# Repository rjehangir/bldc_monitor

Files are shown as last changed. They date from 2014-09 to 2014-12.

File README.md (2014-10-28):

BLDC Monitor
========

The BLDC Monitor is an Arduino compatible board with voltage, current, and RPM sensors for a three-phase brushless motor. The board has components to monitor two motors simultaneously. The software is written in C++ and communicates with a Python program through serial. An ncurses interface allows the motor to be controlled with the arrow keys on the keyboard. Data is displayed in the terminal and also plotted live through Plot.ly.

##Features

* Atmega328p microcontroller
* RPM sensor that uses motor wire for input. An optoisolator protects the rest of the circuit and an active low-pass filter removes high frequency PWM and converts the EMF wave to a binary signal.
* Allegro hall effect current sensors for accurate current measurements
* Measures 2 motors simultaneously

##Interface

The interface is written in Python. It uses the curses, crcmod, serial, and plotly libraries. To run the interface:

```bash
./bldc_monitor.py -p [serial port] -o [csv file to write (optional)]
```

##Releases

TBD

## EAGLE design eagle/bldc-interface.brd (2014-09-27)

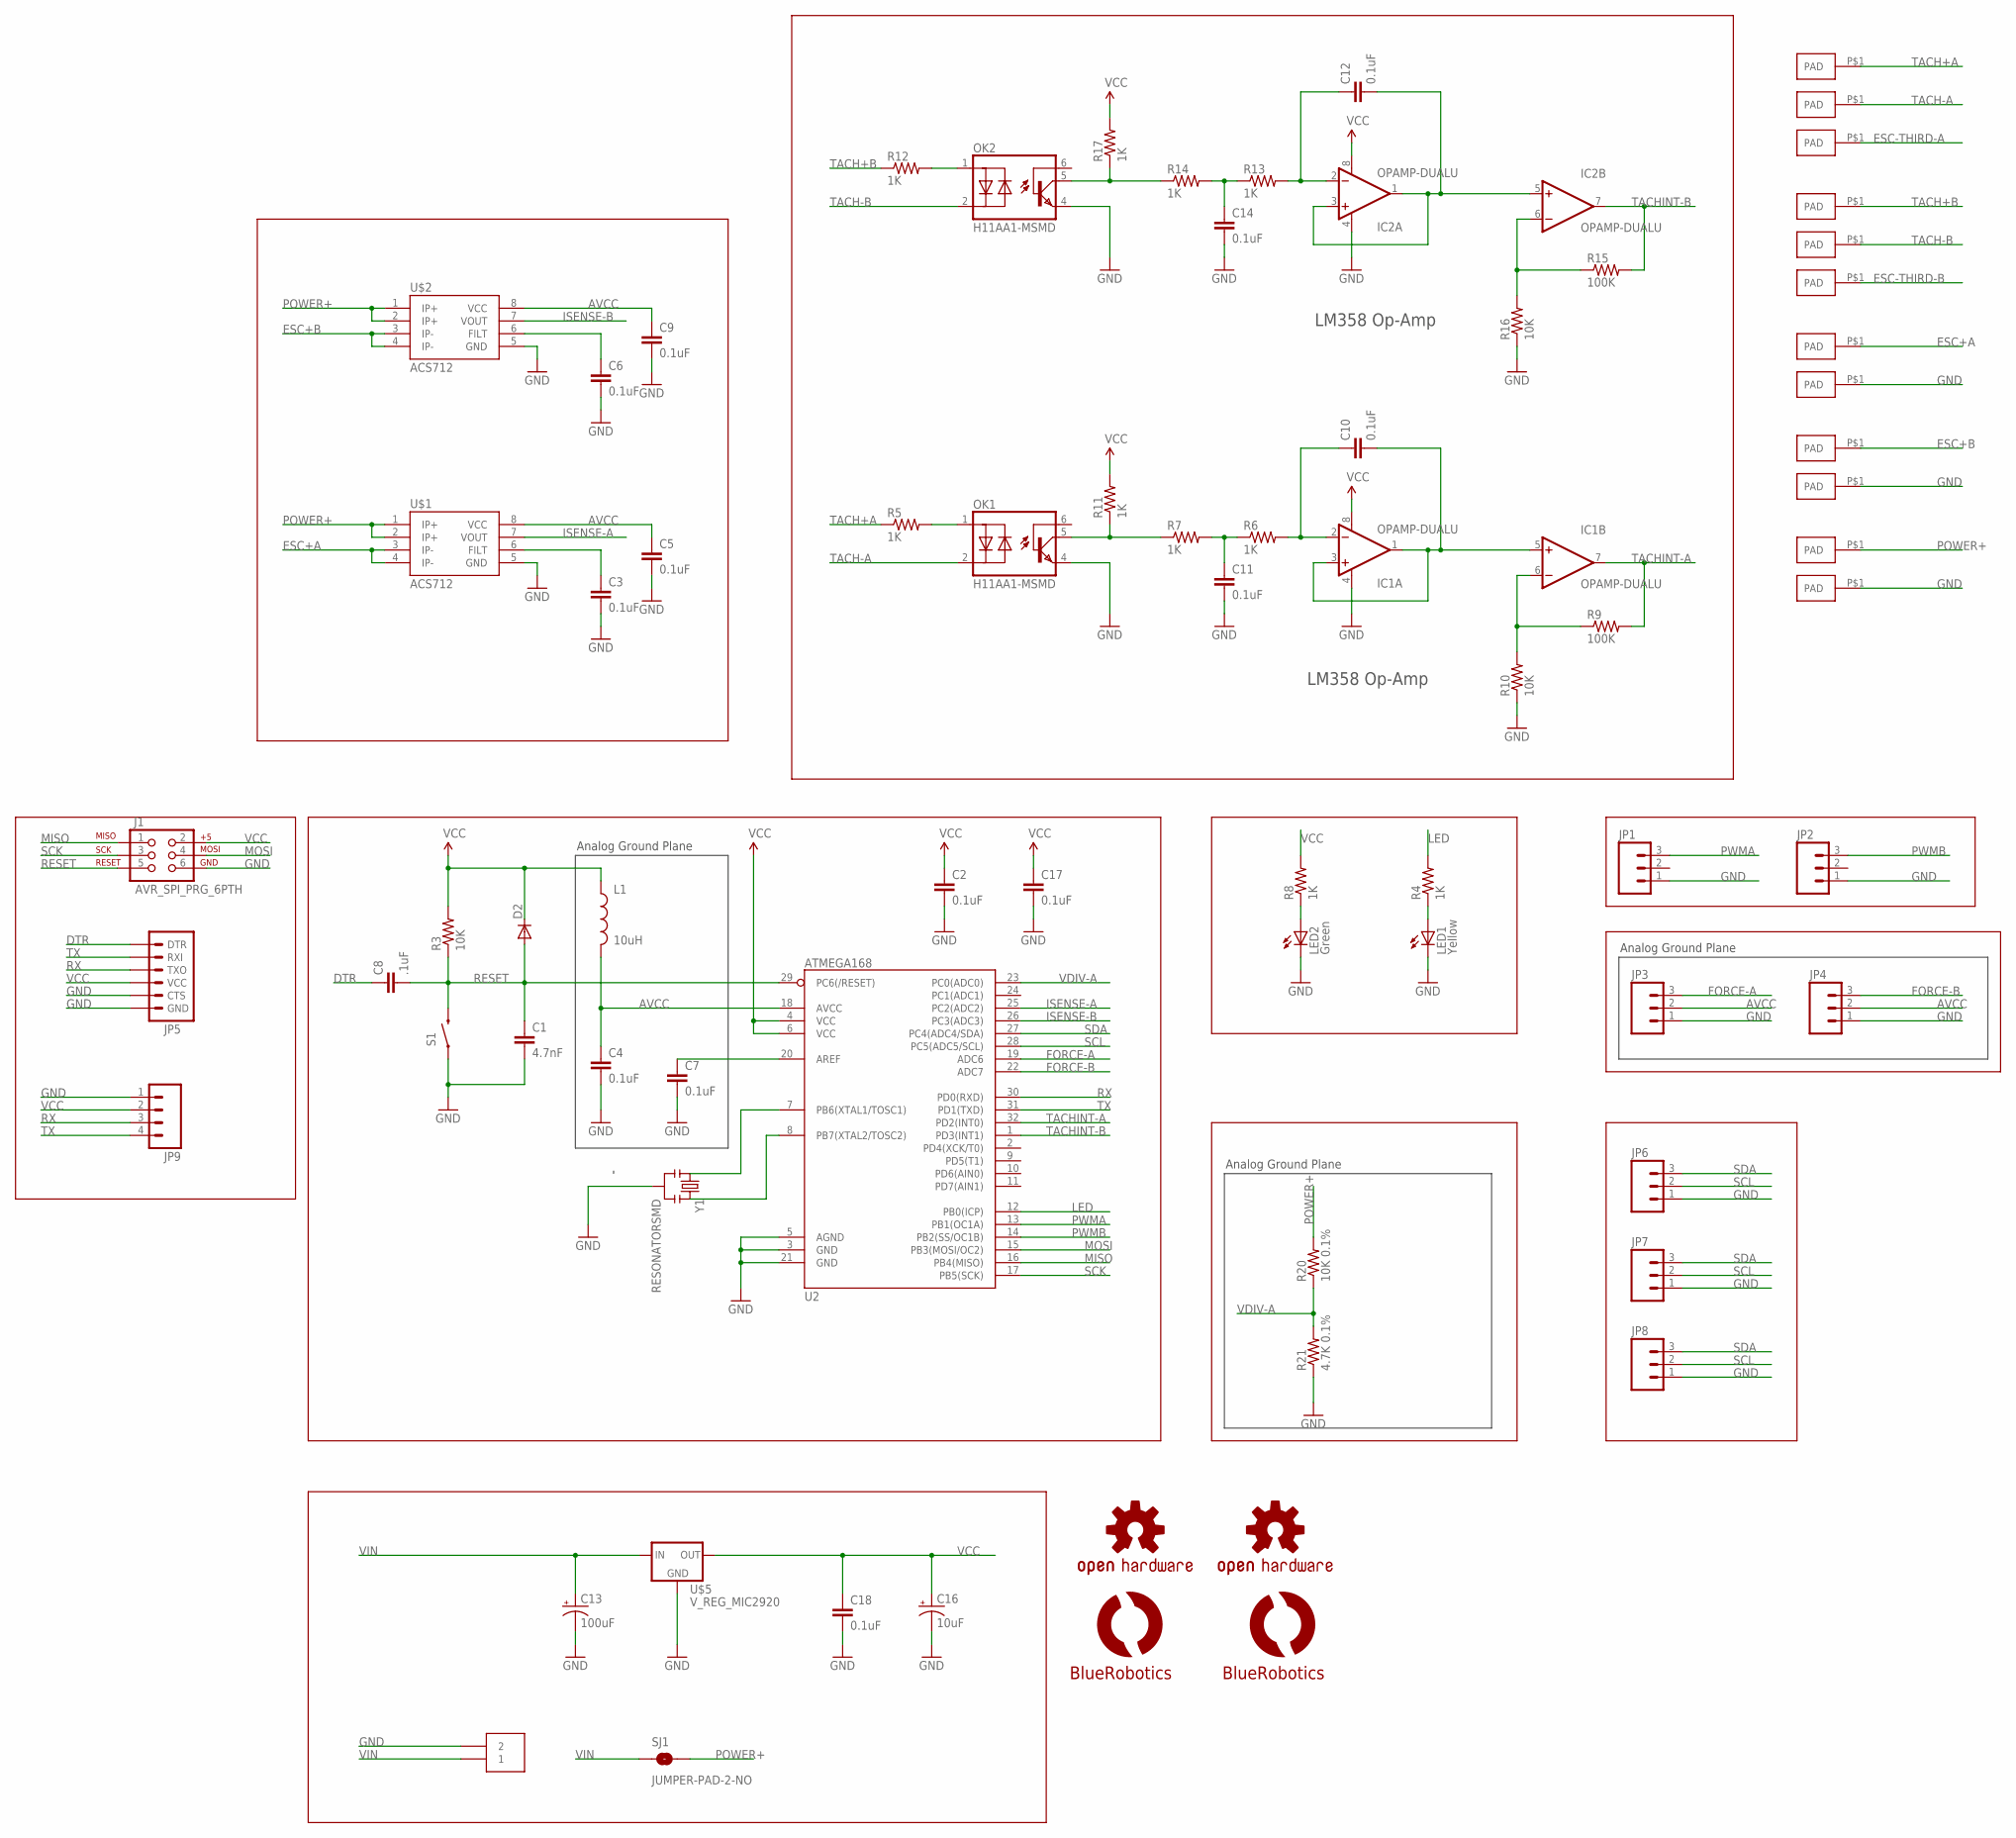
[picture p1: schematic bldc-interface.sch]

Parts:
C1: 4.7nF; 0603-CAP
C2, C3, C4, C5, C6, C7, C9, C10, C11, C12, C14, C17, C18: 0.1uF; 0603-CAP
C8: .1uF; 0603-CAP
C13: 100uF; CPOL-RADIAL-100UF-25V
C16: 10uF; EIA3216
D2: DIODESOD; SOD-323
IC1, IC2: OPAMP-DUALU; SO08
J1: AVR_SPI_PRG_6PTH; 2X3
JP1, JP2, JP3, JP4, JP6, JP7, JP8: M03PTH; 1X03
JP5: ARDUINO_SERIAL_PROGRAMPTH; 1X06
JP9: M04PTH; 1X04
L1: 10uH; 0603
LED1: Yellow; LED-0603
LED2: Green; LED-0603
LOGO1: OSHW-LOGOS; OSHW-LOGO-S
LOGO2: OSHW-LOGOM; OSHW-LOGO-M
OK1, OK2: H11AA1-MSMD; DIL6-SMD
R3, R10, R16: 10K; 0603-RES
R4, R6, R7, R8, R11, R13, R14, R17: 1K; 0603-RES
R5, R12: 1K; R2512
R9, R15: 100K; 0603-RES
R20: 10K 0.1%; 0603-RES
R21: 4.7K 0.1%; 0603-RES
S1: reset; TACTILE_SWITCH_SMD
SJ1: JUMPER-PAD-2-NO; PAD-JUMPER-2-NO_NO_SILK
U2: ATMEGA168; TQFP32-08
U$1, U$2: ACS712; SO08
U$3: TERMINAL-25MM-WEID; LSF-SMT-5MM-2
U$4, U$6, U$7, U$8, U$9, U$10, U$11, U$12, U$13, U$14, U$15, U$16: PADLARGE-ONE-SIDE; PAD-0.2X0.3-ONE-SIDE
U$5: V_REG_MIC2920; SOT223
U$17: LOGOBR-LOGO-M; BR-LOGO-MEDIUM
U$18: LOGOBR-LOGO-S; BR-LOGO-SMALL
Y1: RESONATORSMD; RESONATOR-SMD

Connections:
AVCC: C4.1, C5.1, C9.1, JP3.2, JP4.2, L1.2, U2.18 (AVCC), U$1.8 (VCC), U$2.8 (VCC)
DTR: C8.1, JP5.1 (DTR)
ESC+A: U$1.3 (IP-), U$1.4 (IP-), U$13.P$1
ESC+B: U$2.3 (IP-), U$2.4 (IP-), U$15.P$1
ESC-THIRD-A: U$9.P$1
ESC-THIRD-B: U$12.P$1
FORCE-A: JP3.3, U2.19 (ADC6)
FORCE-B: JP4.3, U2.22 (ADC7)
GND: C1.2, C2.2, C3.2, C4.2, C5.2, C6.2, C7.2, C9.2, C11.2, C13.2 (-), C14.2, C16.C (-), C17.2, C18.2, IC1.4 (V-), IC2.4 (V-), J1.6, JP1.1, JP2.1, JP3.1, JP4.1, JP5.5 (CTS), JP5.6 (GND), JP6.1, JP7.1, JP8.1, JP9.1, LED1.C, LED2.C, OK1.4 (EMI), OK2.4 (EMI), R10.1, R16.1, R21.1, S1.1, U2.3 (GND), U2.5 (AGND), U2.21 (GND), U$1.5 (GND), U$2.5 (GND), U$3.2, U$3.4 (2), U$5.2 (GND), U$8.P$1, U$14.P$1, U$16.P$1, Y1.2
ISENSE-A: U2.25 (PC2(ADC2)), U$1.7 (VOUT)
ISENSE-B: U2.26 (PC3(ADC3)), U$2.7 (VOUT)
LED: R4.2, U2.12 (PB0(ICP))
MISO: J1.1, U2.16 (PB4(MISO))
MOSI: J1.4, U2.15 (PB3(MOSI/OC2))
unnamed: C6.1, U$2.6 (FILT)
unnamed: C3.1, U$1.6 (FILT)
unnamed: LED1.A, R4.1
unnamed: C10.1, IC1.2 (-IN), R6.2
unnamed: C10.2, IC1.1 (OUT), IC1.3 (+IN), IC1.5 (+IN)
unnamed: IC1.6 (-IN), R9.1, R10.2
unnamed: C11.1, R6.1, R7.2
unnamed: C7.1, U2.20 (AREF)
unnamed: U2.7 (PB6(XTAL1/TOSC1)), Y1.1
unnamed: U2.8 (PB7(XTAL2/TOSC2)), Y1.3
unnamed: OK1.5 (COL), R7.1, R11.1
unnamed: C12.1, IC2.2 (-IN), R13.2
unnamed: OK1.1 (A), R5.2
unnamed: C12.2, IC2.1 (OUT), IC2.3 (+IN), IC2.5 (+IN)
unnamed: LED2.A, R8.1
unnamed: C14.1, R13.1, R14.2
unnamed: IC2.6 (-IN), R15.1, R16.2
unnamed: OK2.1 (A), R12.2
unnamed: OK2.5 (COL), R14.1, R17.1
POWER+: R20.2, SJ1.2, U$1.1 (IP+), U$1.2 (IP+), U$2.1 (IP+), U$2.2 (IP+), U$7.P$1
PWMA: JP1.3, U2.13 (PB1(OC1A))
PWMB: JP2.3, U2.14 (PB2(SS/OC1B))
RESET: C1.1, C8.2, D2.2 (A), J1.5, R3.1, S1.3 (2), U2.29 (PC6(/RESET))
RX: JP5.3 (TXO), JP9.3, U2.30 (PD0(RXD))
SCK: J1.3, U2.17 (PB5(SCK))
SCL: JP6.2, JP7.2, JP8.2, U2.28 (PC5(ADC5/SCL))
SDA: JP6.3, JP7.3, JP8.3, U2.27 (PC4(ADC4/SDA))
TACH+A: R5.1, U$6.P$1
TACH+B: R12.1, U$10.P$1
TACH-A: OK1.2 (C), U$4.P$1
TACH-B: OK2.2 (C), U$11.P$1
TACHINT-A: IC1.7 (OUT), R9.2, U2.32 (PD2(INT0))
TACHINT-B: IC2.7 (OUT), R15.2, U2.1 (PD3(INT1))
TX: JP5.2 (RXI), JP9.4, U2.31 (PD1(TXD))
VCC: C2.1, C16.A (+), C17.1, C18.1, D2.1 (C), IC1.8 (V+), IC2.8 (V+), J1.2, JP5.4 (VCC), JP9.2, L1.1, R3.2, R8.2, R11.2, R17.2, U2.4 (VCC), U2.6 (VCC), U$5.3 (OUT)
VDIV-A: R20.1, R21.2, U2.23 (PC0(ADC0))
VIN: C13.1 (+), SJ1.1, U$3.1, U$3.3 (1), U$5.1 (IN)

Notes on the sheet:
Analog Ground Plane
LM358 Op-Amp

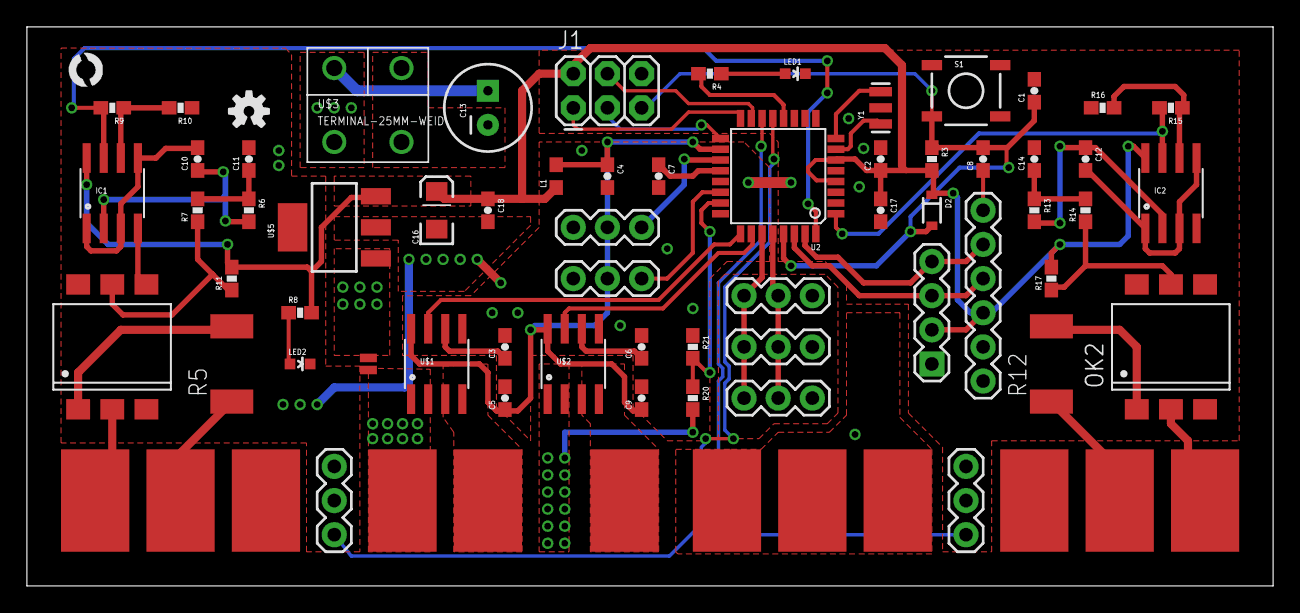
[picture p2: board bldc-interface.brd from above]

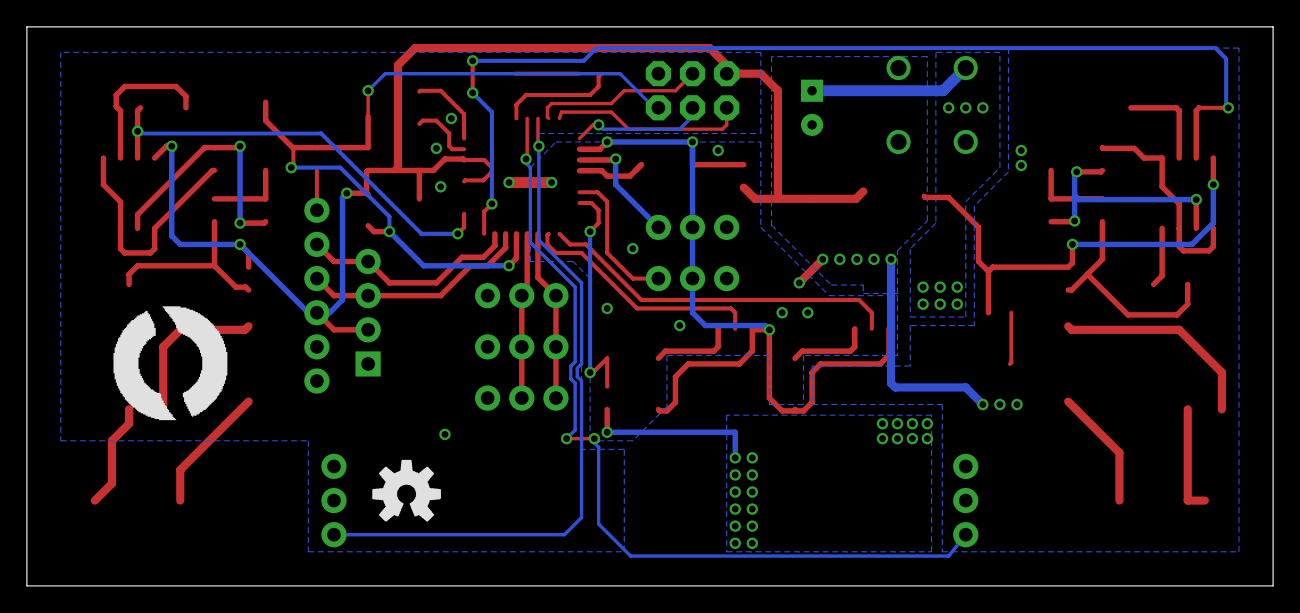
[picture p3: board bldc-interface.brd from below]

Board: 2 copper layers, 92.7 x 41.6 mm, 76 parts (2 on the bottom side), 49 nets.

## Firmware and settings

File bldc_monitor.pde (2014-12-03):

#include <WProgram.h>
#include <util/atomic.h>
#include "Transfer.h"

#define OUTPUT_TRANSFER      1
#define OUTPUT_READABLE      2
#define OUTPUT_PHANT         3
#define INPUT_TRANSFER       1
#define INPUT_READABLE       2
#define INPUT_PHANT          3
#define INPUT_POT            4

#define OUTPUT_TYPE OUTPUT_READABLE
#define INPUT_TYPE INPUT_POT

#define VOLTAGE_SENSE_PIN A0
#define CURRENT_SENSE_PIN_A A2
#define CURRENT_SENSE_PIN_B A3
#define FORCE_SENSE_PIN_A A6
#define FORCE_SENSE_PIN_B A7
#define INPUT_POT_PIN A6
#define TACHOMETER_INT_PIN_A 2
#define TACHOMETER_INT_PIN_B 3
#define SERVO1 9
#define SERVO2 10

#define NUMBER_OF_MOTOR_POLES 12

#define ESC_MIN_PULSE_WIDTH 1100
#define ESC_MAX_PULSE_WIDTH 1900

#define DISTANCE_FROM_PROPELLER_AXIS_TO_PIVOT (11.0f)
#define DISTANCE_FROM_LOAD_CELL_AXIS_TO_PIVOT (12.0f)

#define FORCE_RATIO (DISTANCE_FROM_LOAD_CELL_AXIS_TO_PIVOT/DISTANCE_FROM_PROPELLER_AXIS_TO_PIVOT)

volatile uint32_t pulseCountA = 0;
volatile uint32_t pulseTimerA = 0;
volatile uint32_t lastPulseTimerA = 0;
volatile int32_t ppsA = 0;
volatile uint32_t pulseCountB = 0;
volatile uint32_t pulseTimerB = 0;
volatile uint32_t lastPulseTimerB = 0;
volatile int32_t ppsB = 0;

uint32_t outputTimer = 0;

float thrust = 0;
float tareThrust = 0;

struct BLDCMonitorStruct {
  int16_t rpmA;
  int16_t rpmB;
  float currentA;
  float currentB;
  float voltage;
  float thrust;
  int16_t pwmA;
  int16_t pwmB;
} data;

struct BLDCCommandStruct {
  int16_t pwmA;
  int16_t pwmB;
} command;

Transfer transfer;

/** The following interrupt routine captures pulses from the optocouple/low-pass
 * circuit. A timeout is implemented to prevent counting a single pulse as multiple
 * pulses (basically debouncing the pulse).
 */
ISR(INT0_vect) {
  // Pulses are between 4800 us and 2500 us
  if ( micros()-lastPulseTimerA > 2500 ) {
    pulseCountA++;
    lastPulseTimerA = micros();
  }
  
  if ( pulseCountA > 30 ) {
    ppsA = pulseCountA/(float(micros()-pulseTimerA)/1000000.0f);
    pulseTimerA = micros();
    pulseCountA = 0;
  }
}

ISR(INT1_vect) {
  // Pulses are between 4800 us and 2500 us
  if ( micros()-lastPulseTimerB > 2500 ) {
    pulseCountB++;
    lastPulseTimerB = micros();
  }
  
  if ( pulseCountB > 30 ) {
    ppsB = pulseCountB/(float(micros()-pulseTimerB)/1000000.0f);
    pulseTimerB = micros();
    pulseCountB = 0;
  }
}

/** The RPM measurement is done in the interrupt handling code. If the motor
 * stops then there are no interrupts and therefore the sensor hangs on the final 
 * value instead of going to zero RPM. This function checks for more than 0.1 seconds
 * with no pulses and resets the measurement to zero if necessary. The AVR "atomic"
 * macros are used to prevent this function from being triggered falsely. */
static __inline__ void checkForZeroPulses() {
  uint32_t safePulseTimer = 0;
  ATOMIC_BLOCK(ATOMIC_FORCEON)
  {
    safePulseTimer = pulseTimerA;
  }
  
  if ( micros()-safePulseTimer > 300000l ) {
    ppsA = 0;
  }

  ATOMIC_BLOCK(ATOMIC_FORCEON)
  {
    safePulseTimer = pulseTimerB;
  }
  
  if ( micros()-safePulseTimer > 300000l ) {
    ppsB = 0;
  }
}

/** This function initializes the interrupt (INT0) for the tachometer
 * pulses. It also has code to initialize the servo output, which will be
 * moved to a separate function eventually.
 */
void initTachometer() {
  // Initialize input/output pins
  pinMode(TACHOMETER_INT_PIN_A,INPUT);
  pinMode(TACHOMETER_INT_PIN_B,INPUT);
  pinMode(SERVO1,OUTPUT);
  pinMode(SERVO2,OUTPUT);
  
  // Initialize PWM output for 50 Hz (Digital pin 9)
  TCCR1A = (1<<WGM11)|(1<<COM1A1)|(1<<COM1B1);
  TCCR1B = (1<<WGM13)|(1<<WGM12)|(1<<CS11);
  ICR1 = 40000; // CPU/prescaler/frequency = 16000000/8/50 = 10000 // 50 Hz PWM rate
  
  // Attach the interrupt pins (INT0 and INT1, Arduino Pin 2, 3)
  EICRA |= (1 << ISC00) | (1 << ISC01) | (1 << ISC10) | (1 << ISC11);
  EIMSK |= (1 << INT0) | (1 << INT1);
}

/** This function filters the RPM with a low-pass filter. */
void filterRPM(int16_t &rpm,int16_t newRPM,float dt) {
  const static float tau = 0.25;

  float alpha = dt/(dt+tau);
  
  rpm = rpm*(1-alpha) + newRPM*alpha;
}

/** This function is from http://hacking.majenko.co.uk/making-accurate-adc-readings-on-arduino.
 * It measures the actual value of VCC by comparing it with the Atmega328's internal 1.1V reference,
 * which is more accurate than the voltage regulator. This value can then be used to more
 * accurate measure the analog measurements. 
 *
 * The result is returned as a float.
 */
float readVcc() {
  long result;
  ADMUX = _BV(REFS0) | _BV(MUX3) | _BV(MUX2) | _BV(MUX1);
  delay(2);
  ADCSRA |= _BV(ADSC);
  while (bit_is_set(ADCSRA,ADSC));
  result = ADCL;
  result |= ADCH<<8;
  result = 1125300L / result; // Provides voltage in mV
  return result/1000.0f;
}

/** This function measures the voltage of the power source with the ADC. The
 * power source is connected through a voltage divider consisting of a 10Kohm
 * and 4.7Kohm resistor (2% tolerance). This produces a dividing factor:
 * 
 * V_out/V_in = R1 / (R1 + R2) = 4.7 / (4.7 + 10) = 0.3197
 * 
 * The Atmega328p has a 10-bit ADC and the analog reference voltage is Vcc. Therefore,
 * there are Vcc/1023 V/step. The volts (V) in this expression is the 
 * same as V_out. Therefore,
 * 
 * Vcc/1023 V_out/step x 1/0.3197 V_in/V_out = Vcc*0.00305761 V_in/step
 * 
 * This gives a max reading of 1023*Vcc*0.00306 = 15.6 V_in.
 * 
 * A low pass filter is used to smooth out the analog readings. It has a time constant
 * of 0.1 s and is implemented with a pretty standard discrete formula:
 * 
 * x(k+1) = x(k)*(1-alpha) + u(k+1)*alpha
 * 
 * where x is the output and u is the measured input. Alpha is calculated as
 * 
 * alpha = t/(t+T)
 * 
 * where T is the desired time constant (Tau) and t is period length of the 
 * sampling frequency. For the low pass with time constant of 0.25, and sampling
 * frequency of 100 Hz,
 * 
 * alpha = 0.01/(0.01+0.1) = 0.0909
 */
void measureVoltage(float dt) {
  const static float k = 0.00305761;
  const static float tau = 0.25;
  
  static bool initialized = false;
  if ( !initialized ) {
    initialized = true;
    data.voltage = analogRead(VOLTAGE_SENSE_PIN)*readVcc()*k;
  }
  
  float alpha = dt/(dt+tau);

  data.voltage = data.voltage*(1-alpha) + analogRead(VOLTAGE_SENSE_PIN)*readVcc()*k*alpha;
}

/** This function measure the current supplied from the power source to the speed 
 * controller using a ACS715 current sensor chip. The output of this current 
 * sensor is 0.133 V/A. Like specified above, the Atmega328p has a 10 bit ADC and
 * 5.0 V reference voltage so that it has 0.004883 V/step. Combining this with the
 * current sensor relation provides:
 * 
 * Vcc/1023 V/step x 1/0.133 A/V = Vcc*0.0073498 A/step
 * 
 * The sensor measures 0-30A and is biased at 0.5 V.
 * 
 * A low pass filter is also used on the current measurement to smooth it out
 * slightly. The low pass filter has a time constant of 0.25 s.
 */
void measureCurrent(float dt) {
  #define USE_ACS714
  #ifdef USE_ACS714
  const static float k = 0.01481086525;
  const static float tau = 0.25;
  const static int16_t center = 511; // equivalent to 0.5 V
  #else
  const static float k = 0.0073498;
  const static float tau = 0.25;
  const static int16_t center = 102; // equivalent to 0.5 V
  #endif
  
  static bool initialized = false;
  if ( !initialized ) {
    initialized = true;
    data.currentA = (analogRead(CURRENT_SENSE_PIN_A)-center)*readVcc()*k;
    data.currentB = (analogRead(CURRENT_SENSE_PIN_B)-center)*readVcc()*k;
  }
  
  float alpha = dt/(dt+tau);
  
  data.currentA = data.currentA*(1-alpha) + (analogRead(CURRENT_SENSE_PIN_A)-center)*readVcc()*k*alpha;
  data.currentB = data.currentB*(1-alpha) + (analogRead(CURRENT_SENSE_PIN_B)-center)*readVcc()*k*alpha;
}

/** This function measures the force on the FC22 compression load cell. The load
 * cell is already amplified with an output range of 0.5 to 4.5 V and a measurement
 * range of 0-25 lb. 
 * 
 * The range of the sensor is 4.0 V and the offset is 0.5 V, so that the relationship 
 * between voltage and force is:
 * 
 * F = 25.0/4.0*(V-0.5) = 6.25*(V-0.5)
 * 
 * The voltage can be calculated from:
 * 
 * V = ADC/1023*Vcc = ADC/1023*Vcc
 * 
 * So the resulting relationship is:
 * 
 * F = 6.25*(ADC*Vcc/1023-0.5)
 * 
 * In this measurement scenario, the sensor is preloaded with a tare weight that allows
 * both positive and negative loads to be measured. This function only provides the 
 * measured force without accounting for the tare weight. That must be recorded separately
 * and subtracted from this measurement.
 */
void measureForce(float dt) {
  const static float Kf = 6.25;
  const static float Kadc = 1.0/1023.0;
  const static float offset = 0.5;
  
  const static float tau = 0.1;
  
  float newThrust = Kf*(readVcc()*Kadc*analogRead(FORCE_SENSE_PIN_A)-offset);
  
  float alpha = dt/(dt+tau);
  
  thrust = thrust*(1-alpha) + newThrust*alpha;
}

/** This function sets the tare force to be subtracted from the measured force.
 * It first reads the sensor for 1 second to ensure that the measurement is stable
 * and the first order filter has time to settle. */
void setTareForce() {
  measureForce(100000.0f); // Large dt so that the filter is ignored
  
  for ( uint8_t i = 0 ; i < 100 ; i++ ) {
    measureForce(0.01);
    delay(10);
  }
  
  tareThrust = thrust;
}

/** Calculates the motor thrust from the measured force, tare force, and force ratio
 * based on the moment arm lengths that are defined at the top. */
float getThrust() {
  return (thrust-tareThrust)*FORCE_RATIO;
}

/** Outputs a PWM signal to control the motor controller. Outputs to digital pins 9 and 10. */
void outputPWM(uint16_t _pwmA, uint16_t _pwmB) {
  OCR1A = _pwmA*2;
  OCR1B = _pwmB*2;
}

void setup() {
  Serial.begin(19200);
  initTachometer();
  setTareForce();

  transfer.setStream(&Serial);
  
  outputPWM((ESC_MAX_PULSE_WIDTH+ESC_MIN_PULSE_WIDTH)/2,(ESC_MAX_PULSE_WIDTH+ESC_MIN_PULSE_WIDTH)/2);
  delay(1000);

  command.pwmA = 1500;
  command.pwmB = 1500;
  data.pwmA = command.pwmA;
  data.pwmB = command.pwmB;
}

void loop() {
  
  static long measurementTimer;
  static long outputTimer;
  static long inputTimer;
  
  float dt = float(micros()-measurementTimer)/1000000l;
  
  /** Measurement loop. I would put this in a timer interrupt but since these
   * are relatively long calculations the interrupt could block the RPM pulse
   * interrupt from occuring. */
  if ( dt > 0.005 ) {
    measureVoltage(dt);
    measureCurrent(dt);
    measureForce(dt);
    checkForZeroPulses();
    filterRPM(data.rpmA,ppsA*60/NUMBER_OF_MOTOR_POLES*2,dt);
    filterRPM(data.rpmB,ppsB*60/NUMBER_OF_MOTOR_POLES*2,dt);
    data.thrust = getThrust();
    measurementTimer = micros();
  }
  
  /** Output loop. Output frequency can be adjusted. Currently, the output message
   * is 2+1+1+6*4+2 = 30 bytes = 240 bits/message. Therefore, at 115200 bps, 
   * 
   * 115200 bits/s x 1/240 messages/bit = 480 messages/s
   * 
   * can be sent under ideal conditions. In practice, this number will be lower. */
  static float periodLength = 0.25;
  if ( float(micros()-outputTimer)/1000000l > periodLength ) {
    outputTimer = micros();
    
    switch ( OUTPUT_TYPE ) {
    case OUTPUT_TRANSFER:
			{
        transfer.send(&data);
			}
			break;
    case OUTPUT_READABLE:
			{
        Serial.write(27);       // ESC command
        Serial.print("[2J");    // clear screen command
        Serial.write(27);
        Serial.print("[H");     // cursor to home command
				Serial.println("== Motor A ==");
        Serial.print(getThrust()); Serial.println(" lb");
				Serial.print(data.rpmA); Serial.println(" RPM");
				Serial.print(data.currentA*data.voltage); Serial.println(" W");
        Serial.print(data.currentA); Serial.println(" A");
        Serial.print(data.voltage); Serial.println(" V");
        Serial.print(data.pwmA); Serial.print(" us");
				Serial.println("");
        Serial.println("== Motor B ==");
        Serial.print(getThrust()); Serial.println(" lb");
        Serial.print(data.rpmB); Serial.println(" RPM");
        Serial.print(data.currentB*data.voltage); Serial.println(" W ");
        Serial.print(data.currentB); Serial.println(" A");
        Serial.print(data.voltage); Serial.println(" V");
        Serial.print(data.pwmB); Serial.print(" us");
        Serial.println("");
			}
			break;
    case OUTPUT_PHANT:
      {
        // Set period to 10s so we don't overload Sparkfun
        periodLength = 10;
        Serial.print("voltage=");
        Serial.print(data.voltage,2);
        Serial.print("&current=");
        Serial.print(data.currentA,2);
        Serial.print("&power=");
        Serial.print(data.currentA*data.voltage,1);
        Serial.print("&rpm=");
        Serial.print(float(data.rpmA),0);
        Serial.print("&thrust=");
        Serial.print(getThrust(),2);
        Serial.print("&signal=");
        Serial.print(float(data.pwmA),0);
        Serial.println("");
      }
      break;
		default:
			Serial.println("Must define OUTPUT_TYPE.");    
    } 
  }

  // Sweep through throttle
  if (false) {
    static bool initialized = false;
    static long startTime;
    if ( !initialized ) {
      startTime = millis();
      initialized = true;
    }
    //static long startTime = millis();
    command.pwmA = 410*sin(2*PI/60*(millis()-startTime)/1000.0f)+(ESC_MIN_PULSE_WIDTH+ESC_MAX_PULSE_WIDTH)/2;
    outputPWM(command.pwmA,command.pwmA);
    data.pwmA = command.pwmA;
  }
  
  /** Serial input to control motor speed */
  if ( float(micros()-inputTimer)/1000000l > 0.1 ) {
    inputTimer = micros();
    switch (INPUT_TYPE) {
    case INPUT_TRANSFER:
      if ( transfer.receive(&command) ) {
        outputPWM(command.pwmA,command.pwmA);
        data.pwmA = command.pwmA;
        data.pwmB = command.pwmB;
      }  
      break;
    case INPUT_PHANT:
      if (Serial.available() > 0) {
        uint8_t buffer[32];
        uint8_t thrusterToSet = Serial.read();

        for ( uint8_t i = 0 ; i < 32 ; i++ ) {
          buffer[i] = Serial.read();
          if ( buffer[i] == '\n' || buffer[i] == '\r' || buffer[i] == '\0' ) {
            buffer[i] = '\0';
            break;
          }
        }

        if ( thrusterToSet == 'a' ) {
          command.pwmA = constrain(atoi(reinterpret_cast<const char*>(buffer)),1000,2000);
        } else if ( thrusterToSet == 'b' ) {
          command.pwmB = constrain(atoi(reinterpret_cast<const char*>(buffer)),1000,2000);
        }
        data.pwmA = command.pwmA;
        data.pwmB = command.pwmB;
        outputPWM(command.pwmA,command.pwmB);
      }
      break;
    case INPUT_READABLE:
      if (Serial.available() > 0) {
        command.pwmA = map(Serial.read(),0,256,ESC_MIN_PULSE_WIDTH,ESC_MAX_PULSE_WIDTH);
        outputPWM(command.pwmA,command.pwmA);
      }
      break;
    case INPUT_POT:
      {
        static const float alpha = 0.1/(0.25+0.1);
        static float potentiometer = 1500;

        potentiometer = potentiometer*(1-alpha) + analogRead(INPUT_POT_PIN)*alpha;

        data.pwmA = map(potentiometer,0,1023,1100,1900);
        data.pwmB = data.pwmA;
        outputPWM(data.pwmA,data.pwmB);
      }
      break;
    }
  }

}

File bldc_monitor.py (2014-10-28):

#!/usr/bin/python 

import numpy as np
import serial
import crcmod
import struct
import time
import datetime
import plotly.plotly as py
from optparse import OptionParser
import json
import signal
import sys
import csv

class SerialConnection:
	def openConnection(self,port,baudrate):
		self.ser = serial.Serial(port,baudrate,timeout=0.05,writeTimeout=0)
		time.sleep(1.0)
		if self.ser.isOpen():
			print "Serial port opened."
	
	## This function is temporary for testing purposes.
	def readMessageFake(self):
		formatString = 'HHfff'
		return np.random.normal(size=struct.calcsize(formatString))
		
	def read(self,length):
		preamble = ['\xFF','\xFA'];
		input = [0x00,0x00]
		input[1] = self.ser.read(1)
		while ( True ):
			if ( input == preamble ):
				break
			else:
				input[0] = input[1]
				input[1] = self.ser.read(1)
		
		while ( self.ser.inWaiting() < length + 2 ):
			pass

		#Get data
		data = self.ser.read(length)

		#Get checksum
		input = self.ser.read(2)
		checksum = struct.unpack('H',input)[0]

		#Verify checksum
		crc16 = crcmod.mkCrcFun(0x11021,0xFFFF,True)
		calcChecksum = crc16(data)
		calcChecksum = (~calcChecksum) % 2**16  # convert to uint16_t

		if ( checksum != calcChecksum ):
			print "Failed checksum."
			return
		      
		return data

class PlotlyPlotter:
	def initPlotly(self):
		with open('./config.json') as config_file:
			plotly_user_config = json.load(config_file)

		username = plotly_user_config['plotly_username']
		api_key = plotly_user_config['plotly_api_key']
		stream_tokens = plotly_user_config['plotly_streaming_tokens']
		stream_server = 'http://stream.plot.ly'

		py.sign_in(username, api_key)

		numPoints = 450

		trace0 = {'x':[],'y':[],'type': 'scatter', 'stream': {'token': stream_tokens[0], 'maxpoints': numPoints}}
		trace1 = {'x':[],'y':[],'yaxis':'y2','type': 'scatter', 'stream': {'token': stream_tokens[1], 'maxpoints': numPoints}}
		trace2 = {'x':[],'y':[],'yaxis':'y3','type': 'scatter', 'stream': {'token': stream_tokens[2], 'maxpoints': numPoints}}
		trace3 = {'x':[],'y':[],'yaxis':'y4','type': 'scatter', 'stream': {'token': stream_tokens[3], 'maxpoints': numPoints}}

		xAxisStyle = {'title':'Time'}

		domainHeight = 0.22
		domainGap = (1.0-4*domainHeight)/3.0

		layout1 = { 'title':'Thruster-100 Live Test Data',
			    'showlegend': False,
			    'xaxis':xAxisStyle,
			    'yaxis':{'domain':[0,domainHeight],'title':'Voltage (V)'},
			    'yaxis2':{'domain':[domainHeight+domainGap,2*domainHeight+domainGap],'title':'Power (W)'},
			    'yaxis3':{'domain':[2*domainHeight+2*domainGap,3*domainHeight+2*domainGap],'title':'RPM'},
			    'yaxis4':{'domain':[3*domainHeight+3*domainGap,4*domainHeight+3*domainGap],'title':'Thrust (lb)'}}

		r = py.iplot({'data':[trace0, trace1, trace2, trace3],'layout':layout1},filename='Thruster-Stream',fileopt='overwrite')
		print r

		self.s0 = py.Stream(stream_tokens[0])
		self.s1 = py.Stream(stream_tokens[1])
		self.s2 = py.Stream(stream_tokens[2])
		self.s3 = py.Stream(stream_tokens[3])
		
		self.s0.open()
		self.s1.open()
		self.s2.open()
		self.s3.open()
		
	def closePlotly(self):
		self.s0.close()
		self.s1.close()
		self.s2.close()
		self.s3.close()
	
	def streamToPlotly(self,data):
		timeStamp = datetime.datetime.now().strftime('%Y-%m-%d %H:%M:%S.%f')
		trace0 = {'x': timeStamp, 'y': data[0]}
		trace1 = {'x': timeStamp, 'y': data[1]}
		trace2 = {'x': timeStamp, 'y': data[2]}
		trace3 = {'x': timeStamp, 'y': data[3]}
		self.s0.write(trace0)
		self.s1.write(trace1)
		self.s2.write(trace2)
		self.s3.write(trace3)
		
class CumulativeTimeMeter:
		def init(self):
				self.startTime = time.time()
				self.fileName = 'hourmeter.log'
				with open(self.fileName,'r') as f:
						try:
								oldRecord = json.load(f)
						except ValueError, e:
								oldRecord = {'cumulativeTime':0,'cumulativeRPSxTime':0,'cumulativeThrustxTime':0}
								with open(self.fileName,'w') as f2:
										json.dump(oldRecord,f2)
				self.oldTime = oldRecord['cumulativeTime']
				self.oldRPSTime = oldRecord['cumulativeRPSxTime']
				self.oldThrustTime = oldRecord['cumulativeThrustxTime']
				self.time = 0
				self.rpsTime = 0
				self.thrustTime = 0
				self.lastTime = time.time()
				
		def getCumulativeTime(self):
				return self.time+self.oldTime
				
		def getCumulativeRPSxTime(self):
				return self.rpsTime + self.oldRPSTime
				
		def getCumulativeThrustxTime(self):
				return self.thrustTime + self.oldThrustTime		
				
		def meterTime(self,isMetering,rpm,thrust):
				delta = time.time() - self.lastTime
				self.lastTime = time.time()
				
				if isMetering:
						self.time += delta
						self.rpsTime += delta*rpm/60.0
						self.thrustTime += delta*thrust
				
		def recordCumulativeTime(self):
				record = {'cumulativeTime':self.getCumulativeTime(),'cumulativeRPSxTime':self.getCumulativeRPSxTime(),'cumulativeThrustxTime':self.getCumulativeThrustxTime()}
				with open(self.fileName,'w') as f:
						json.dump(record,f)
				

#######################################

meter = CumulativeTimeMeter()

meter.init()

sercon = SerialConnection()

parser = OptionParser()
parser.add_option("-o","--output",dest="filename",help="Output file name.",metavar="FILE")
parser.add_option("-p","--port",dest="portname")
(options,args) = parser.parse_args()

isFile = False
if options.filename:
	csvfile = open(options.filename,'w')
	csvwriter = csv.writer(csvfile,delimiter=',')
	isFile = True

connected = False
try:
	sercon.openConnection(options.portname,19200)
	connected = True
except:
	connected = False
	print "Error connecting to serial port. Defaulting to random data."

plotter = PlotlyPlotter()

plotter.initPlotly()

import curses
stdscr = curses.initscr()
curses.cbreak()
stdscr.keypad(1)
stdscr.nodelay(1)

stdscr.addstr(0,0,"Thrust Test Stand")
stdscr.addstr(1,0,"============================")
stdscr.addstr(3,0,"Adjust motor:\tUp/down, pgup/pgdown, scroll wheel")
stdscr.addstr(4,0,"Stop motor: \tSPACE")
stdscr.addstr(5,0,"Quit: \t\tq")
if connected:
	stdscr.addstr(15,0,"Live serial data.")
else:
	stdscr.addstr(15,0,"Simulated data.")
stdscr.refresh()

command = 1500
streamCount = 0
values = []

def sigint_handler(*args):
	print "Closing serial port."
	sercon.ser.close()
	print "Quiting gracefully."
	time.sleep(0.25)
	sys.exit()

def getMotorFromTerminal():
	global command
	
 	key = stdscr.getch()
	
	if key == curses.KEY_UP:
		  command += 5
		  if command > 1900:
			  command = 1900
	elif key == curses.KEY_DOWN:
		  command -= 5
		  if command < 1100:
			  command = 1100
	elif key == curses.KEY_PPAGE:
		  command += 50
		  if command > 1900:
			  command = 1900
	elif key == curses.KEY_NPAGE:
		  command -= 50
		  if command < 1100:
			  command = 1100
	elif key == ord(' '):
		  command = 1500
	elif key == ord('q'):
		  command = 1500
		  if connected:
			sercon.ser.write(chr(command))
		  plotter.closePlotly()
		  curses.endwin()
		  sercon.ser.close()
		  exit()
		  
	stdscr.addstr(8,5,"Motor command: "+str(command)+"     ")
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

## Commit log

2013-12-06 Added basic files. No work has really been done yet but the directory structure is set up. The entire repository is structure to allow the entire folder to be copied into the Arduino "libraries" dire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
2013-12-06 Restructured files slightly so that the directory could be copied into the Arduino libraries folder easily.
2013-12-09 After getting a single basic plot to work, I added three other plots and labeled them for voltage, current, power, and rpm. This will eventually be done dynamically but it is hardcoded for now. The x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
2013-12-09 Added a text box in the upper right corner of each plot to display the current value of the data. The text item is a little jumpy because PyQtGraph only allows TextItems to be positioned relative to 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
2013-12-09 Tested the code with an Arduino outputting serial data. It works correctly although the handling of a failed checksum in less than great. The program defaults to using the "fake" serial port that gen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
2013-12-11 Copied plotuinoAnalog sketch to plotuinoBLDC, which will measure voltage, current, RPM, and force generated by a brushless motor. The data will be plotted for analysis.
2013-12-11 Added a voltage measuring function for the BLDC measuring tool. It is well documented and should be fairly easy to modify if a different voltage divider, ADC, or filter is used.
2013-12-11 Fixed two "no return statement in non-void function" errors so that it compiles properly.
    [plotuinoBLDC.pde]
2013-12-11 Change the low pass filter in the voltage measuring function to recalculate alpha at every loop so as to avoid instability caused by variable loop periods.
    [plotuinoBLDC.pde]
2013-12-11 Finished adding the voltage, current, and rpm measurement functions. The main loop is also complete. Measurements are made at 200 Hz and output is sent at 10 Hz. These values are arbitrary and can be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
    [plotuinoBLDC.pde]
2013-12-11 Added center offset for current sensor, which is a plus/minus sensor. This was missing before.
    [plotuinoBLDC.pde]
2013-12-13 Tested the embedded code with the Python code and fixed a few bugs. It is working now and the voltage/current/power/RPM example is functioning.
    [plotuinoBLDC.pde]
2013-12-15 Adjusted the hard-coded value for the center of the analog current sensor to match empirical value.
2014-01-11 Added RPM/V (Kv) to the BLDC example and the plotuino file. Remember, eventually the plotuino.py file will be generic and configured through the Arduino communication.
2014-02-05 Added a thrust plot and appropriate data field to the Arduino code.
2014-02-21 Added the necessary functions to measure thrust with the FC22 0-25 lb force sensor. There is still no factor for the moment arm, but that will be added shortly.
    [plotuinoBLDC.pde]
2014-02-21 Added a factor to account for different distance from the pivot point. The FORCE_RATIO is multiplied by the measured force to get the actual thrust force.
2014-04-25 Integrated working plotly code with plotuino.py code and it seems to be working well. Haven't tested it with the actual Arduino yet.
2014-04-25 Updated Arduino output to match the Plotly plot output. The old plots need to be updated to reflect this as well.
2014-04-26 Fixed a few constants.
    [plotuinoBLDC.pde]
2014-04-27 Added curses to the plotlyuino code to allow the motor to be controlled from Arduino. Also added the needed code to the Arduino. It reads in a byte that is incremented with the arrow or pg up/down ke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
2014-04-27 Fixed the low pass filters on the arduino code.
    [plotuinoBLDC.pde]
2014-04-29 Added a little more info to the ncurses display including data type (simulated vs. serial) and number of stream points sent to Plotly. I wish Plotly had some feedback status information I could print.
2014-04-29 Changed precision of several values being printed in the curses display for ease of reading
2014-04-30 Put serial reading and sending to plotly in separate timing loops so that the serial data can be read at a high rate to absorb and freezing and the plotly data can be appropriately throttled.
2014-06-08 Added an hour meter functionality that counts the time the passes and stores it constantly to a file as a json readable object. When the program is restarted, it reads the value from the file and con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
2014-06-09 Added much more functionality to the cumulative hour meter. It now also logs time x RPM and time x thrust to provide average values of each. It also only logs when the RPM is greater than zero.
2014-06-20 Creates a new hourmeter log if the current one cannot be read properly.
2014-06-21 Modified the code for the BR BLDC monitor board and for the Afro ESC which can run in both directions.
2014-06-21 Restructured the project. It is no longer an attempt to make a generic Arduino plotting tool but to make a BLDC monitoring tool. That had already happened but now it is official. I deleted all files 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
    [bldc_monitor.pde, bldc_monitor.py]
2014-06-22 Updated to work with INT0 instead of INT1 since that pin is being used on the BLDC monitor board for motor A. Note that none of the motor B sensors have been added to software yet. Everything is work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
2014-06-23 Fixed error in the current sensor that would cause the current to appear higher than it actually was.
    [bldc_monitor.pde]
2014-07-01 Modified the analog measurement code to first measure the value of Vcc compared to the internal 1.1V reference. This value is then used in all the other ADC measurements to provide a more accurate va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
2014-07-01 Added defines for the min and max pulse widths sent to the ESC.
2014-07-08 Added switch statement for different output types and added a blank for the EasyTransfer library method. Still need to add the struct for that library and the actual methods.
2014-07-16 Removed dependency on EasyTransfer library which will be replaced with my 'Transfer' library.
    [bldc_monitor.pde]
2014-07-18 Added Transfer class and the needed functions to send the bldc data as a c struct over serial. Should also add this to the python program and do away with the 'comm.*' files.
2014-07-18 Added motor B to the bldc_monitor. This hasn't been tested yet, but theoretically it should be able to monitor and output data for two motors simultaneously.
2014-09-12 Minor changes to the monitor. Having issues sending commands in a timely manner.
    [bldc_monitor.pde, bldc_monitor.py]
2014-09-25 Fixed some stupid mistakes that must have crept in a while ago. RPM measurement is working correctly now.
    [bldc_monitor.pde, bldc_monitor.py]
2014-09-27 Added Eagle files for the BLDC monitor, rev1.
    [bldc-interface.brd, bldc-interface.sch]

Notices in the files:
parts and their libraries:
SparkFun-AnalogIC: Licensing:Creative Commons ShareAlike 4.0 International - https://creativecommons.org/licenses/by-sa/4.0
